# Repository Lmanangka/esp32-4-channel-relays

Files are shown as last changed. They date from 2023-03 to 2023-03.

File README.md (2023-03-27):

# PCB Design for 4-Channel Relays Based on ESP32-WROOM-32 Module

This repository contains the PCB design files, schematic, and 3D model image
for a 4-channel relay board based on the ESP32-WROOM-32 module. The board is
designed for controlling various electronic devices such as light, fans,
motors, and more.

## Features

- Four independently controllable 5V relays.
- ESP32-WROOM-32 module for wireless connectivity and easy programming.
- Terminal block for easy integration to the electronic devices.
- USB TYPE-C connector for power and programming
- Small form factor for easy integration into any project.

## Repository Contents

- **PCB design files**: The KiCad project files for the PCB design.
- **Schematic**: The circuit diagram of the design.
- **3D model image**: A preview image of the 3D model of the board.

## PCB Design

The PCB design is created using KiCad, an open-source software suite for
electronic design automation(EDA). The design files include the Schematic, the
PCB layout, and the Gerber files required for manufacturing.

The board include four 5V relays, each of which is controlled by a GPIO pin of
the ESP32-WROOM-32 module. The module is also responsible for wireless
connectivity and easy programming of the board. Terminal blocks are provided
for easy connection to the electronic devices. The board also includes a USB
TYPE-C connector for power and programming, providing a more robust and
versatile interface than traditional USB connectors.

## Schematic

The Schematic shows the circuit diagram of the design, including the
ESP32-WROOM-32 module, the relays, and the other components of the board.

## 3D Model Image

The 3D model image provides a preview of what the board looks like in a 3D view.
This can be usefule for visualizing the board and how it will fit into your
project.

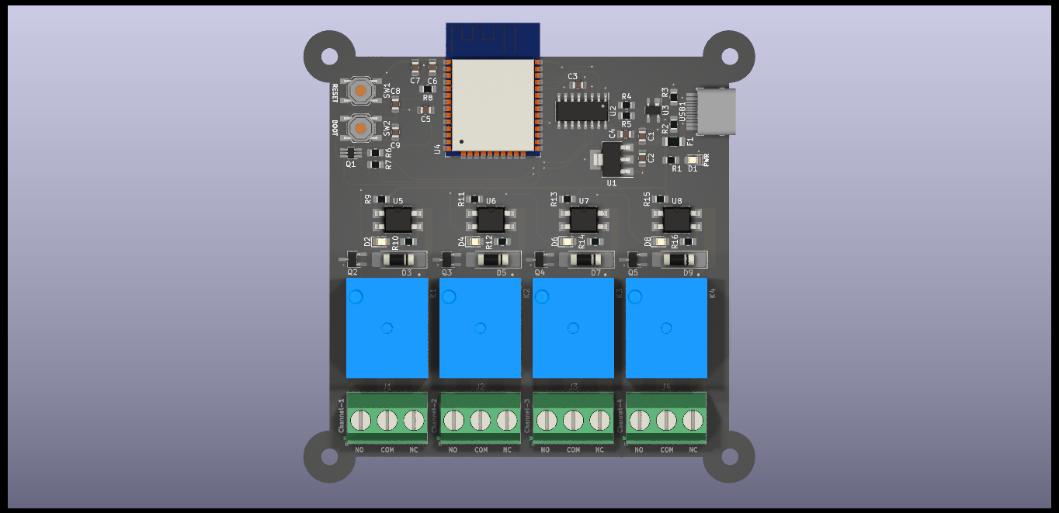
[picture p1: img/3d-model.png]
3D Model Image


## License

This design is released under the CERN Open Hardware License Version 2 - Permissive.
You are free to use, modify, and distribute the design as long as you include
the license file in your distribution. See the [LICENSE](https://github.com/Lmanangka/esp32-4-channel-relays/blob/main/LICENSE)
file for details.

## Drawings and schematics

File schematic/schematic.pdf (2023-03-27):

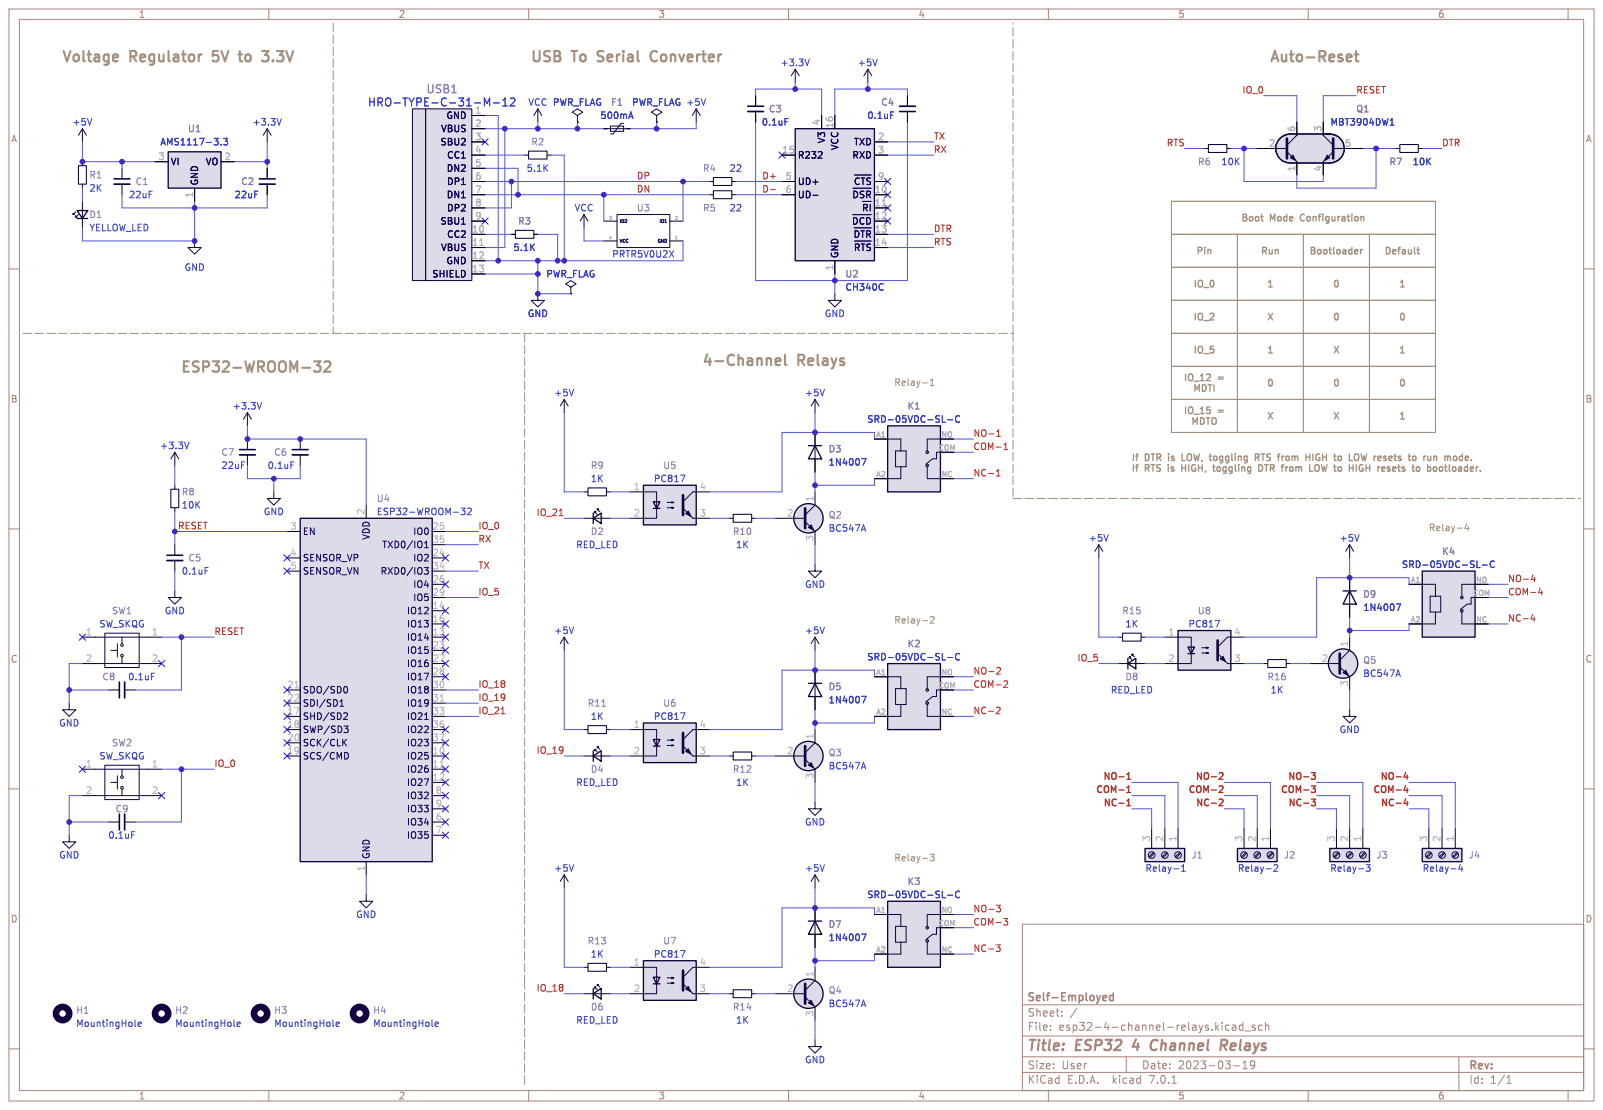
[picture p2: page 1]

GND 1 CC2 10 VBUS 11 GND 12 SHIELD 13 VBUS 2 SBU2 3 CC1 4 DN2 5 DP1 6 DN1 7 DP2 8 SBU1 9 USB1

4 UD+ 5 UD- 6 ~{CTS}9 U2 CH340C GND

1 ~{DSR} 10 ~{RI} 11 ~{DCD} 12 ~{DTR} 13 ~{RTS} 14 R232 15 VCC 16 TXD 2 RXD 3 V3

File: esp32-4-channel-relays.kicad_sch Sheet: / Self-Employed GND

4 UD+ 5 UD- 6 ~{CTS}9 K2 SRD-05VDC-SL-C

If RTS is HIGH, toggling DTR from LOW to HIGH resets to bootloader. Relay-1

If DTR is LOW, toggling RTS from HIGH to LOW resets to run mode.

2 SCK/CLK 20 SDO/SD0 21 SDI/SD1 22

Id: 1/1 Title: ESP32 4 Channel Relays

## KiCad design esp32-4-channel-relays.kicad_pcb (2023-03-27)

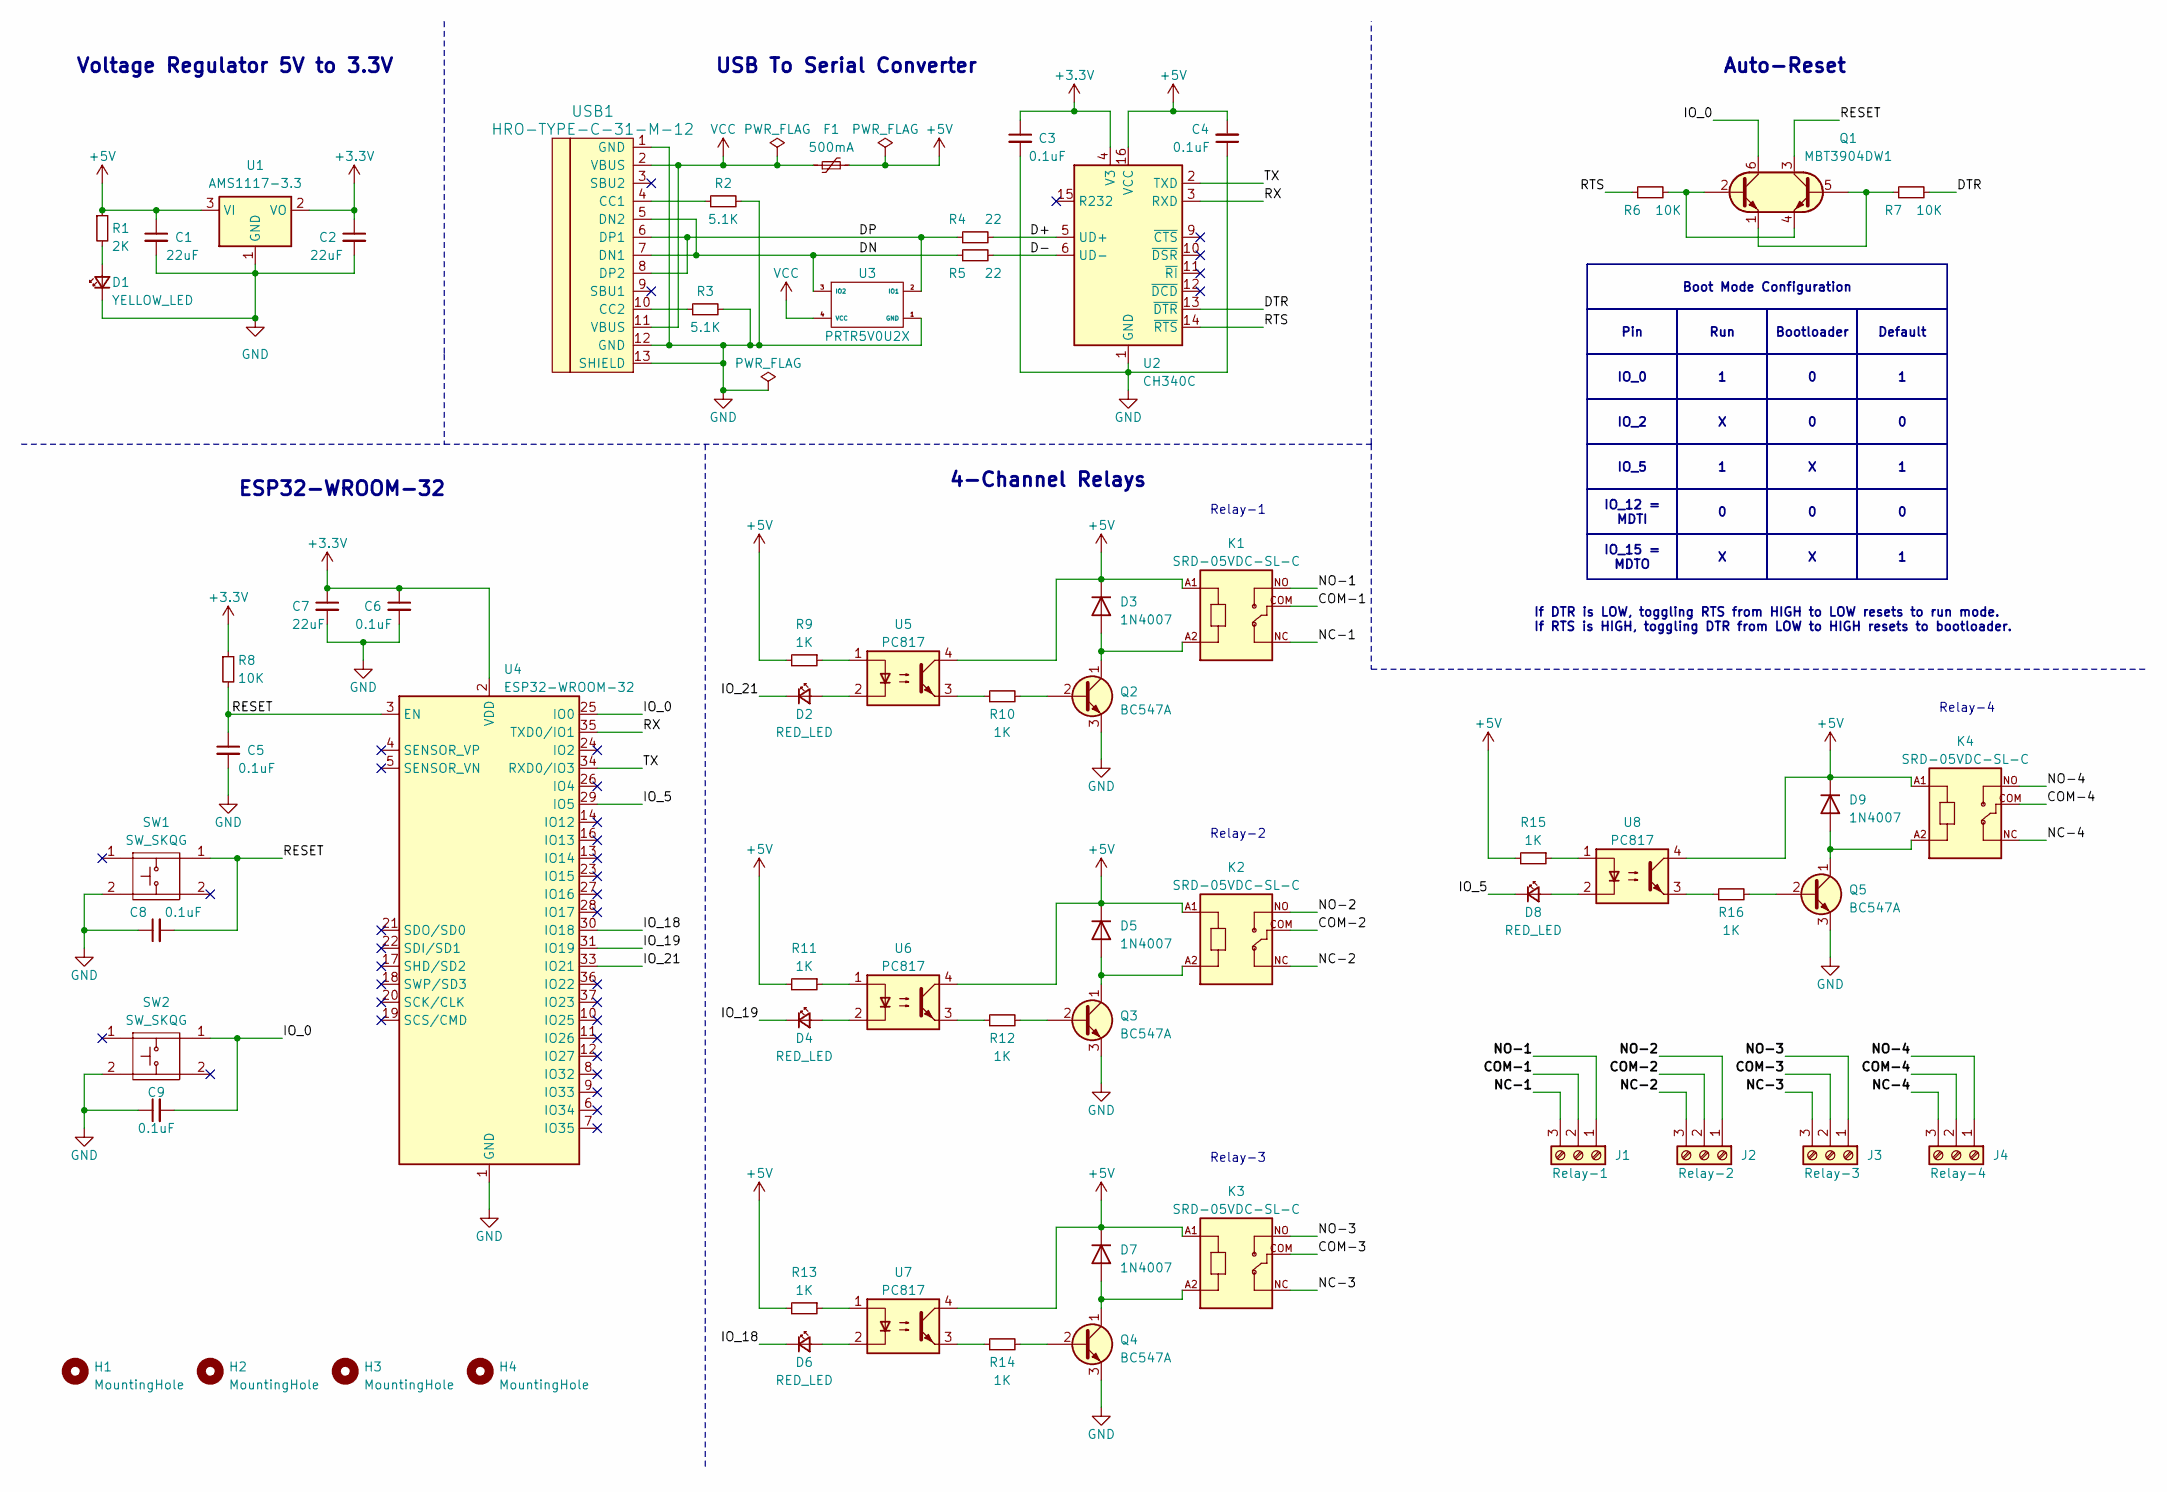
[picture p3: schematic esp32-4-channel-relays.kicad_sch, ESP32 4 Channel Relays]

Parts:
C1, C2, C7: 22uF; C_0805_2012Metric_Pad1.18x1.45mm_HandSolder
C3, C4, C5, C6, C8, C9: 0.1uF; C_0805_2012Metric_Pad1.18x1.45mm_HandSolder
D1: YELLOW_LED; LED_0805_2012Metric_Pad1.15x1.40mm_HandSolder
D2, D4, D6, D8: RED_LED; LED_0805_2012Metric_Pad1.15x1.40mm_HandSolder
D3, D5, D7, D9: 1N4007; D_MELF_Handsoldering
F1: 500mA; Fuse_1206_3216Metric_Pad1.42x1.75mm_HandSolder
H1, H2, H3, H4: MountingHole; MountingHole_3.2mm_M3
J1: Relay-1; TerminalBlock_Phoenix_MKDS-1,5-3-5.08_1x03_P5.08mm_Horizont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
J2: Relay-2; TerminalBlock_Phoenix_MKDS-1,5-3-5.08_1x03_P5.08mm_Horizont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
J3: Relay-3; TerminalBlock_Phoenix_MKDS-1,5-3-5.08_1x03_P5.08mm_Horizont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
J4: Relay-4; TerminalBlock_Phoenix_MKDS-1,5-3-5.08_1x03_P5.08mm_Horizont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
K1, K2, K3, K4: SRD-05VDC-SL-C; RELAY_SRD-05VDC-SL-C
Q1: MBT3904DW1; SOT-363_SC-70-6_Handsoldering
Q2, Q3, Q4, Q5: BC547A; TSOT-23_HandSoldering
R1: 2K; R_0805_2012Metric_Pad1.20x1.40mm_HandSolder
R2, R3: 5.1K; R_0805_2012Metric_Pad1.20x1.40mm_HandSolder
R4, R5: 22; R_0805_2012Metric_Pad1.20x1.40mm_HandSolder
R6, R7, R8: 10K; R_0805_2012Metric_Pad1.20x1.40mm_HandSolder
R9, R10, R11, R12, R13, R14, R15, R16: 1K; R_0805_2012Metric_Pad1.20x1.40mm_HandSolder
SW1, SW2: SW_SKQG; SW_SPST_SKQG_WithStem
U1: AMS1117-3.3; SOT-223-3_TabPin2
U2: CH340C; SOIC-16_3.9x9.9mm_P1.27mm
U3: PRTR5V0U2X; SOT-143_Handsoldering
U4: ESP32-WROOM-32
U5, U6, U7, U8: PC817; SMDIP-4_W7.62mm
USB1: HRO-TYPE-C-31-M-12; HRO-TYPE-C-31-M-12-HandSoldering

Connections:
+3.3V: C2.1, C3.1, C6.1, C7.1, R8.1, U1.2 (VO), U2.4 (V3), U4.2 (VDD)
+5V: C1.1, C4.2, D3.1 (K), D5.1 (K), D7.1 (K), D9.1 (K), F1.2, K1.A1, K2.A1, K3.A1, K4.A1, R1.1, R9.2, R11.2, R13.2, R15.2, U1.3 (VI), U2.16 (VCC), U5.4, U6.4, U7.4, U8.4
/COM-1: J1.2, K1.COM
/COM-2: J2.2, K2.COM
/COM-3: J3.2, K3.COM
/COM-4: J4.2, K4.COM
/D+: R4.2, U2.5 (UD+)
/D-: R5.2, U2.6 (UD-)
/DN: R5.1, U3.3 (IO2), USB1.5 (DN2), USB1.7 (DN1)
/DP: R4.1, U3.2 (IO1), USB1.6 (DP1), USB1.8 (DP2)
/DTR: R7.2, U2.13 (~DTR)
/IO_0: C9.2, Q1.6 (C1), SW2.1, U4.25 (IO0)
/IO_5: D8.1 (K), U4.29 (IO5)
/IO_18: D6.1 (K), U4.30 (IO18)
/IO_19: D4.1 (K), U4.31 (IO19)
/IO_21: D2.1 (K), U4.33 (IO21)
/NC-1: J1.3, K1.NC
/NC-2: J2.3, K2.NC
/NC-3: J3.3, K3.NC
/NC-4: J4.3, K4.NC
/NO-1: J1.1, K1.NO
/NO-2: J2.1, K2.NO
/NO-3: J3.1, K3.NO
/NO-4: J4.1, K4.NO
/RESET: C5.1, C8.2, Q1.3 (C2), R8.2, SW1.1, U4.3 (EN)
/RTS: R6.1, U2.14 (~RTS)
/RX: U2.3 (RXD), U4.35 (TXD0/IO1)
/TX: U2.2 (TXD), U4.34 (RXD0/IO3)
GND: C1.2, C2.2, C3.2, C4.1, C5.2, C6.2, C7.2, C8.1, C9.1, D1.1 (K), Q2.3 (E), Q3.3 (E), Q4.3 (E), Q5.3 (E), R2.2, R3.2, SW1.2, SW2.2, U1.1 (GND), U2.1 (GND), U3.1 (GND), U4.1 (GND), U4.15 (GND), U4.38 (GND), U4.39 (GND), USB1.1 (GND), USB1.12 (GND), USB1.13 (SHIELD)
unnamed: D1.2 (A), R1.2
unnamed: D2.2 (A), U5.2
unnamed: D3.2 (A), K1.A2, Q2.1 (C)
unnamed: D4.2 (A), U6.2
unnamed: D5.2 (A), K2.A2, Q3.1 (C)
unnamed: D6.2 (A), U7.2
unnamed: D7.2 (A), K3.A2, Q4.1 (C)
unnamed: D8.2 (A), U8.2
unnamed: D9.2 (A), K4.A2, Q5.1 (C)
unnamed: Q1.2 (B1), Q1.4 (E2), R6.2
unnamed: Q1.1 (E1), Q1.5 (B2), R7.1
unnamed: Q2.2 (B), R10.2
unnamed: Q3.2 (B), R12.2
unnamed: Q4.2 (B), R14.2
unnamed: Q5.2 (B), R16.2
unnamed: R9.1, U5.1
unnamed: R10.1, U5.3
unnamed: R11.1, U6.1
unnamed: R12.1, U6.3
unnamed: R13.1, U7.1
unnamed: R14.1, U7.3
unnamed: R15.1, U8.1
unnamed: R16.1, U8.3
unnamed: R2.1, USB1.4 (CC1)
unnamed: R3.1, USB1.10 (CC2)
VCC: F1.1, U3.4 (VCC), USB1.2 (VBUS), USB1.11 (VBUS)

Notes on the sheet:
Default
IO_2
IO_15 = MDTO
Bootloader
IO_0
IO_12 = MDTI
Run
Boot Mode Configuration
IO_5
Pin
Voltage Regulator 5V to 3.3V
4-Channel Relays
Relay-1
Relay-4
Relay-3
Relay-2
Auto-Reset
ESP32-WROOM-32
If DTR is LOW, toggling RTS from HIGH to LOW resets to run mode. If RTS is HIGH, toggling DTR from LOW to HIGH resets to bootloader.
USB To Serial Converter

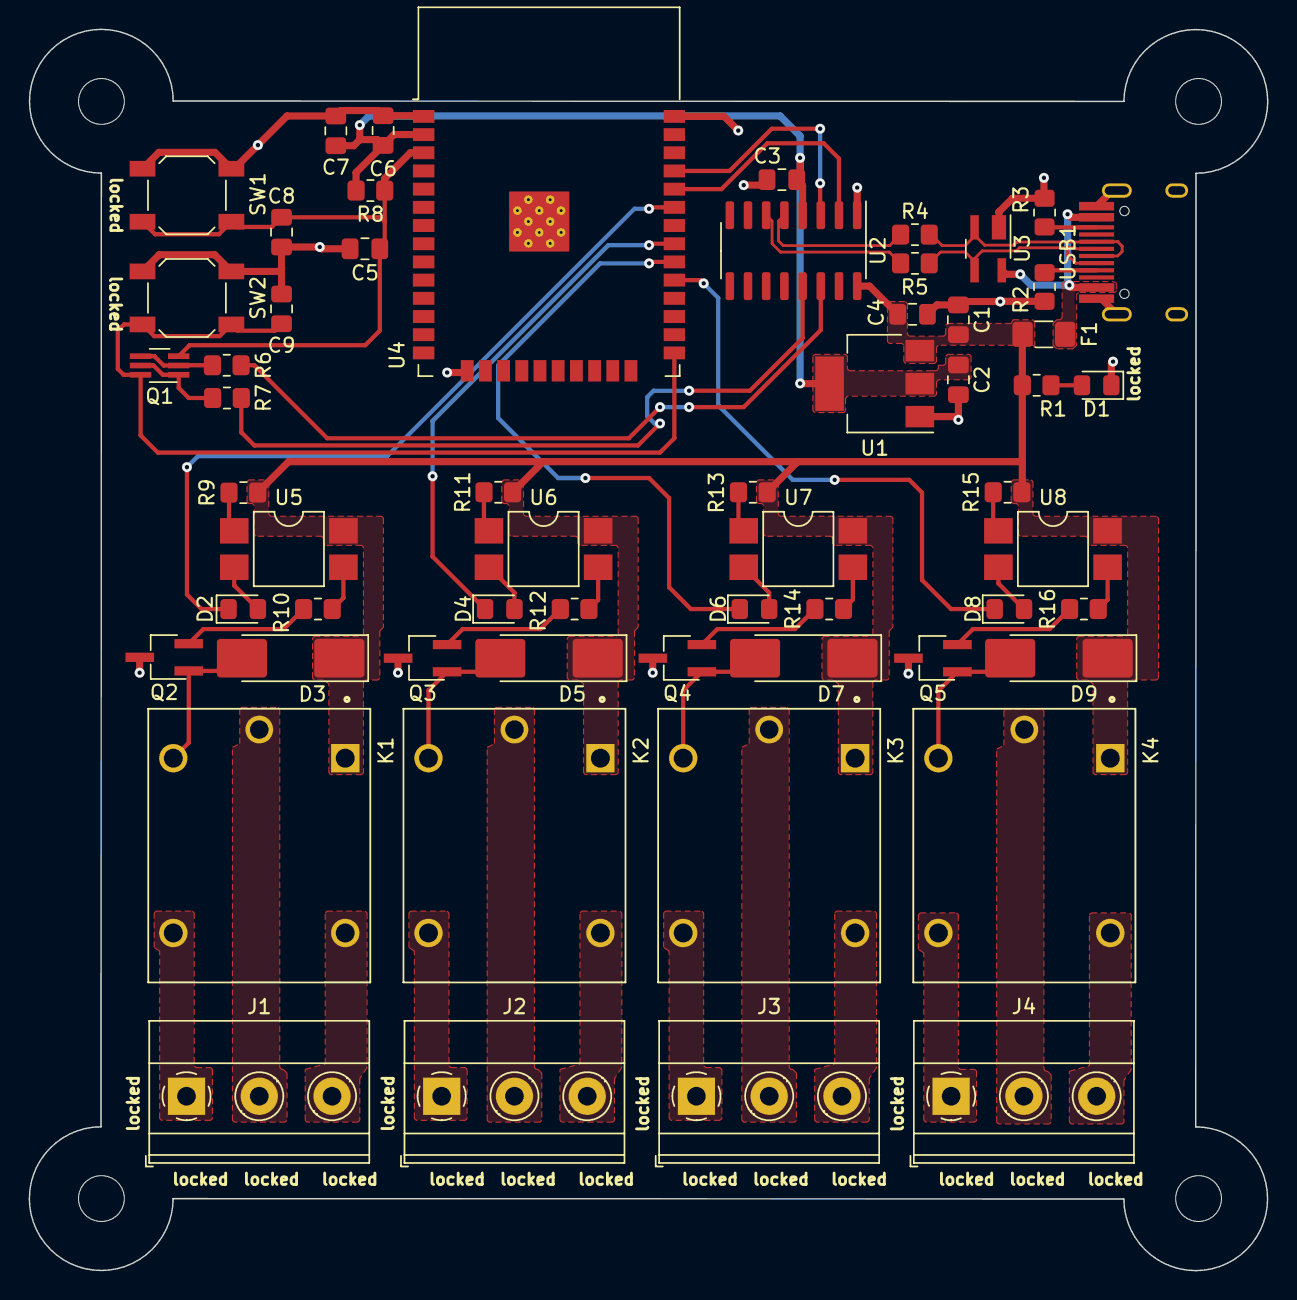
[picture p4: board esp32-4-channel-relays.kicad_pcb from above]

Board: 2 copper layers, 86.4 x 86.6 mm, 63 parts (0 on the bottom side), 55 nets.

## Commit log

2023-03-19 Add empty KiCad files
    [esp32-4-channel-relays.kicad_pcb, esp32-4-channel-relays.kicad_sch]
2023-03-19 Add esp32-4-channel-relays-backups to gitignore
2023-03-19 Add voltage regulator 5V to 3.3V
    [esp32-4-channel-relays.kicad_sch]
2023-03-19 Add USB to serial converter
    [esp32-4-channel-relays.kicad_sch]
2023-03-19 Add auto-reset
    [esp32-4-channel-relays.kicad_sch]
2023-03-19 Add ESP32-WROOM-32 and reset button and boot button
    [esp32-4-channel-relays.kicad_sch]
2023-03-20 Update library add relay, optocoupler and transistor symbols
2023-03-20 Add 4-channel relays to the schematic
    [esp32-4-channel-relays.kicad_sch]
2023-03-20 Add screw terminal for relay output and wiring relay input to esp32 GPIO
    [esp32-4-channel-relays.kicad_sch]
2023-03-20 Add 3d model for USB Type-C and Relay 5V
2023-03-20 Add footprint for components other than resistors and capacitors
2023-03-20 Add project footprint library
2023-03-20 Assign footprint to project symbol library
2023-03-20 Assign footprints
    [esp32-4-channel-relays.kicad_sch]
2023-03-21 Load schematic to PCB Editor
    [esp32-4-channel-relays.kicad_pcb]
2023-03-21 Make temporary edge cut and relays placement
    [esp32-4-channel-relays.kicad_pcb]
2023-03-22 USB Type-C and Voltage regulator 3.3V placement
    [esp32-4-channel-relays.kicad_pcb]
2023-03-22 ESP32, auto-reset and buttons placement also a little tweak to USB to serial converter placement
    [esp32-4-channel-relays.kicad_pcb]
2023-03-22 Add mounting hole symbols and assign footprint
    [esp32-4-channel-relays.kicad_sch]
2023-03-22 Add mounting hole to pcb editor and redraw edgecut
    [esp32-4-channel-relays.kicad_pcb]
2023-03-22 Add fill zone and routing VCC, 5V and 3.3V power
    [esp32-4-channel-relays.kicad_pcb]
2023-03-22 Routing relays
    [esp32-4-channel-relays.kicad_pcb]
2023-03-22 Routing Reset, Reset switch button and IO_0, IO_0 switch button
    [esp32-4-channel-relays.kicad_pcb]
2023-03-22 Routing GND, RTS and DTR
    [esp32-4-channel-relays.kicad_pcb]
2023-03-22 Reconnect relays to esp32 considering footprint placement
    [esp32-4-channel-relays.kicad_sch]
2023-03-22 Routing relays to esp32 and design rules check
    [esp32-4-channel-relays.kicad_pcb]
2023-03-22 Add 3d model for switch button and link it to switch button footprint
2023-03-23 Design rules check and lock components
    [esp32-4-channel-relays.kicad_pcb]
2023-03-23 Add Labels for relays, switch button and LED power indicator
    [esp32-4-channel-relays.kicad_pcb]
2023-03-27 Update page setting
    [esp32-4-channel-relays.kicad_pcb, esp32-4-channel-relays.kicad_sch]
2023-03-27 Add schematic
